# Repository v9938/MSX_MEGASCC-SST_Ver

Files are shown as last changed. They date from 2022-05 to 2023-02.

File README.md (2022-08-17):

# MSX MEGA-SCC (似非SCC) SST Flash version  

SCCのFlash CartridgeとしてMEGA-SCC(似非SCC)が有名ですが、
使用しているFlash ROM AM29F040Bの入手が近年難しいのが難点でした。  
  
そこで、入手が容易なSST社のFlash ROMでなんとかならんかと  
HRA!(@thara1129)さんが思いついたAddress入れ替えによるMEGA-SCCを基板化したものが本製品になります。

原案：  
<https://github.com/hra1129/MSX_MegaSCC_for_SST39SF040>

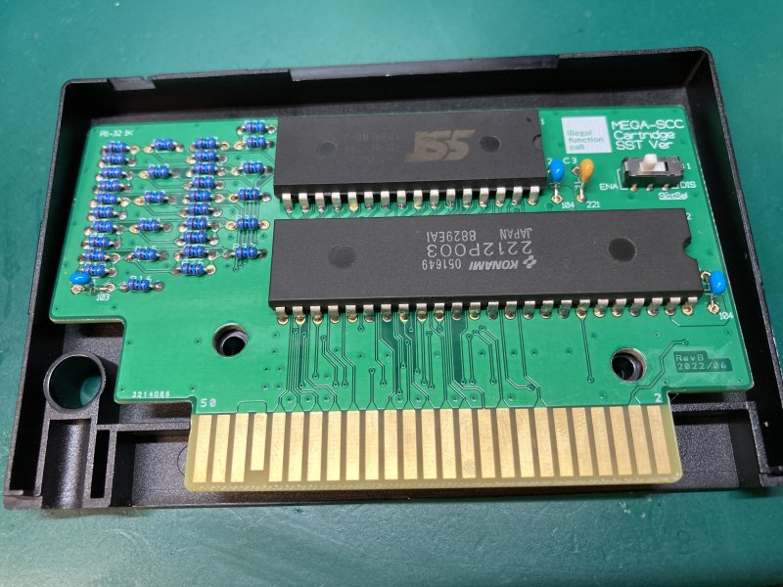
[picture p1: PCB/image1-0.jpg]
  

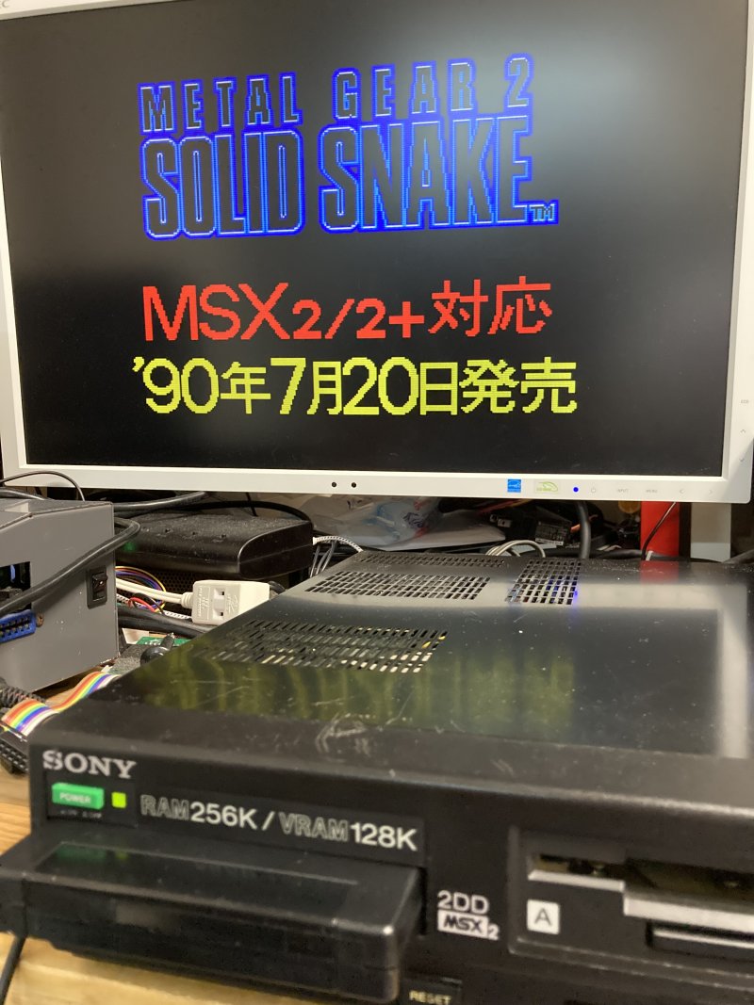
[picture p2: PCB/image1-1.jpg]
  

## ■ 本製品のキット頒布について

下記2ショップで取り扱っていただいています。  

家電のKENちゃん  
<https://www.kadenken.com/view/item/000000001450>  

BEEPさん  
<https://www.beep-shop.com/ec/products/detail/26575>  

本キットの組み立てにはSCC (2212P003) を実カートリッジから取り外す必要があります。  

DACのKONAMI051650については取り外し不要です。  
基板上に等価回路を実装しています。  

シェルはKONAMIのMSX CassetteまたはRGR製のTransparent Cartridge Shell for MSX Konami-styleに対応しています。

## ■ KONAMI純正シェルを使用する方へのお願い（RevA/B 基板）

当方の基板サイズの計測ミスでケースと干渉することが分かりました。  
使用する場合は、干渉する左上3x8mm程度をカットするようにお願いします。（下記図参考)  
なお、当該部分は配線などが無いため動作に影響はありません。  

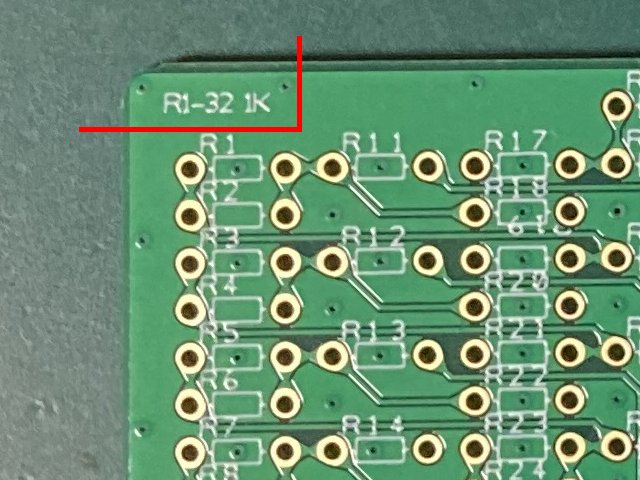
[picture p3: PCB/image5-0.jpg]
  

## ■ SCCとの結線について

HRA!(@thara1129)さんの方法通りです。A12とMA15を入れ替えます。
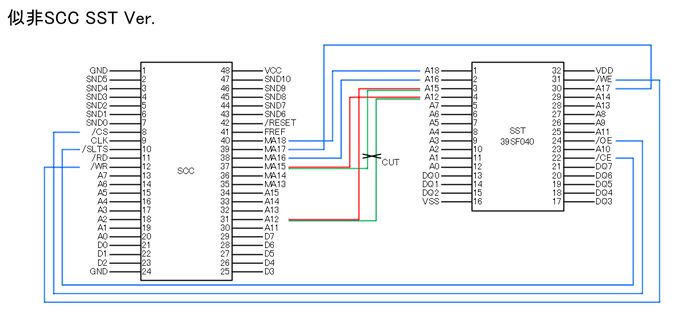
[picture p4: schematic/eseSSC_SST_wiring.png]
  

## ■ カートリッジ基板について

回路図、および基板のガーバデータを同梱しています。  
  
SCCチップ(2212P003)については、実カートリッジから取り外して実装してください。  
DACのKONAMI051650については、取り外しの難易度が高いのでHICの等価回路を基板上に実装しています。  
  
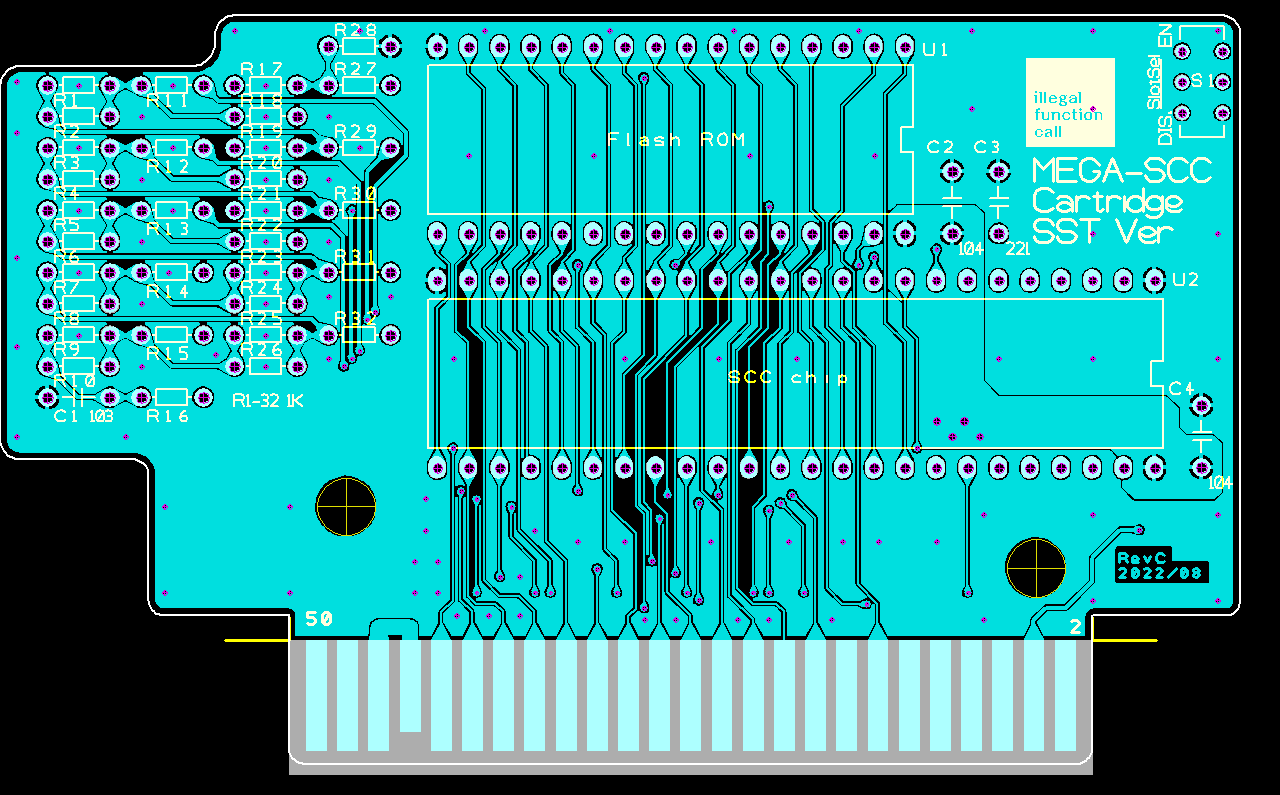
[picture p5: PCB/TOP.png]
  
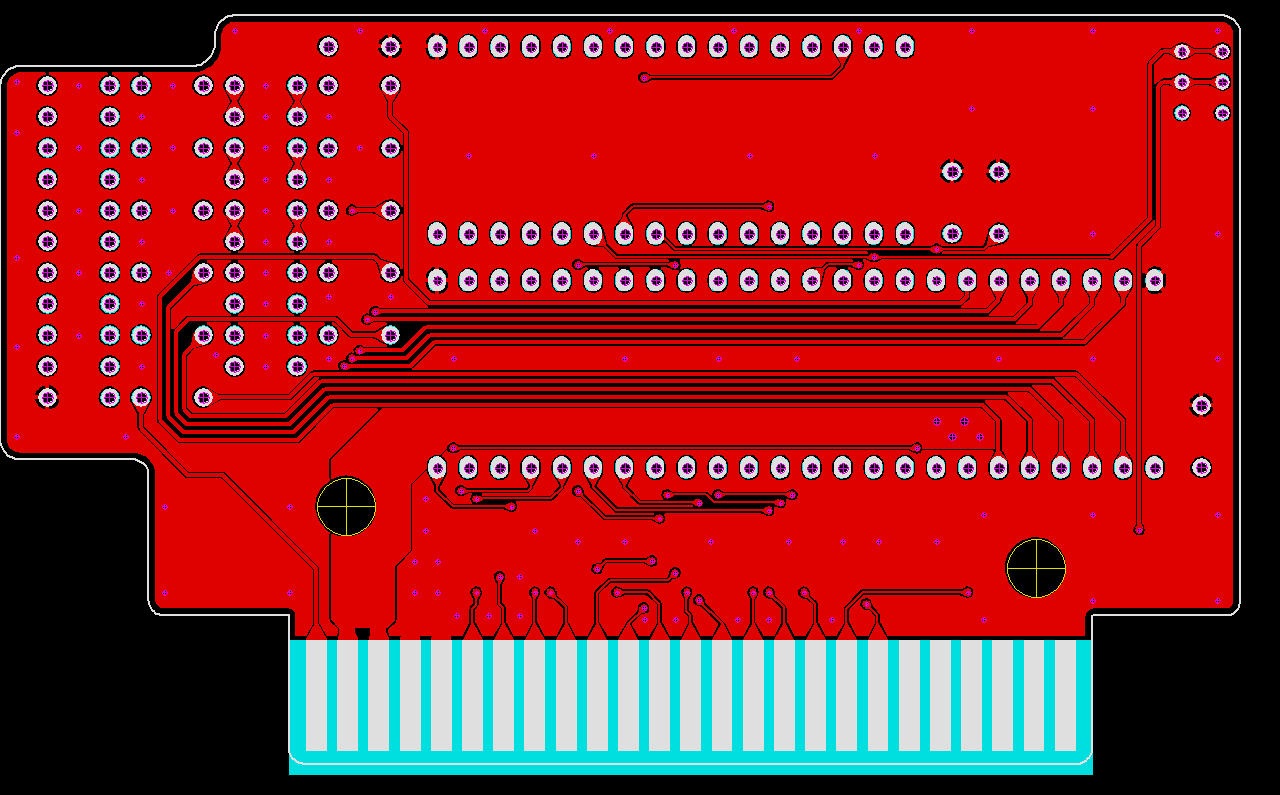
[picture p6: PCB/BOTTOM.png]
    

## ■ 回路図

全体の回路図については下記を参照してください。
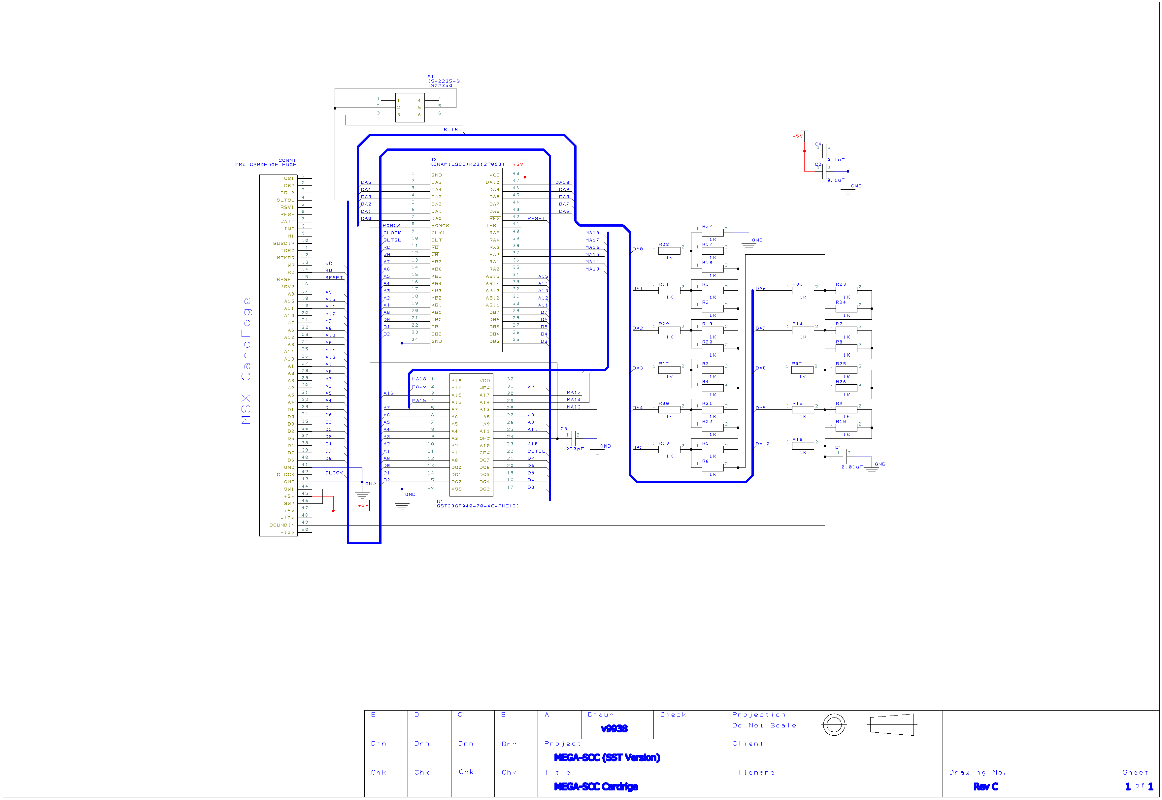
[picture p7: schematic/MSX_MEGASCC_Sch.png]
  

## ■ 部品表

| 部品番号 | 部品名 |
|---|---|
| U1  | Flash ROM SST39SF040 |
| U2  | KONAMI SCC CHIP 2212P003 |
| C1  | 積層セラミック コンデンサー0.01uF (103) |
| C2/C4  | 積層セラミック コンデンサー0.1uF (104) |
| C3  | 積層セラミック コンデンサー220pF (221) |
| R1-32  | 1KΩ(5%) 1/8W |
| S1  | スイッチ IS-2235 (RevB～)|  

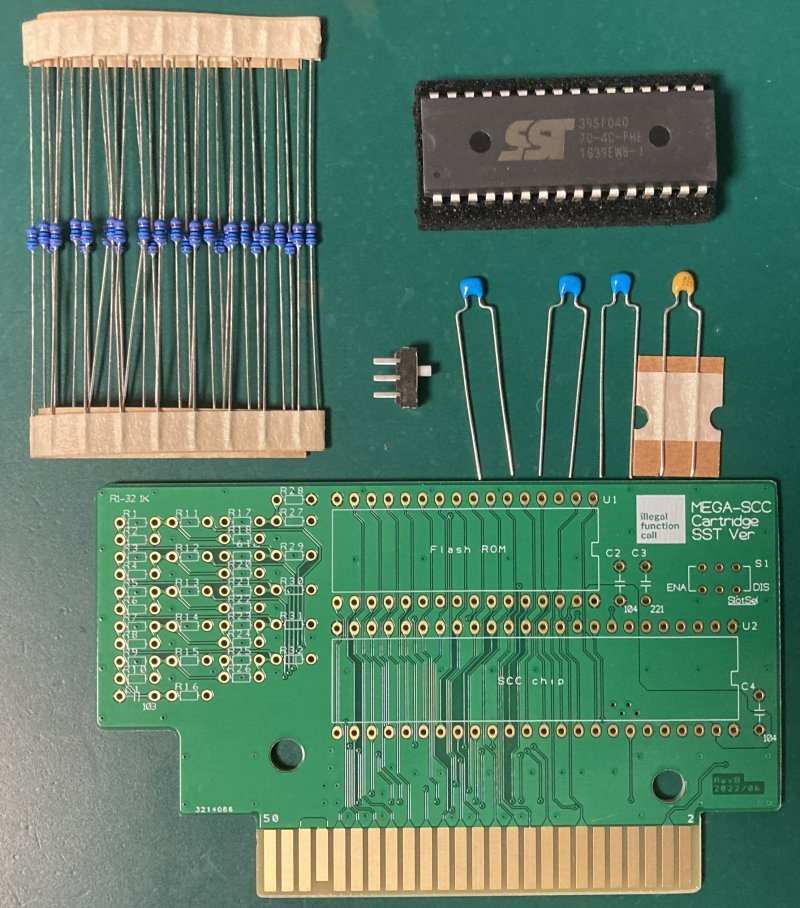
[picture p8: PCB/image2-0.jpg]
  

## ■ 基板の組み立て方法

セオリー通り背の低い部品から半田付けしてください。  
ICソケットを使うとケースに入らなくなるので注意してください。  

1．R1-32を実装  
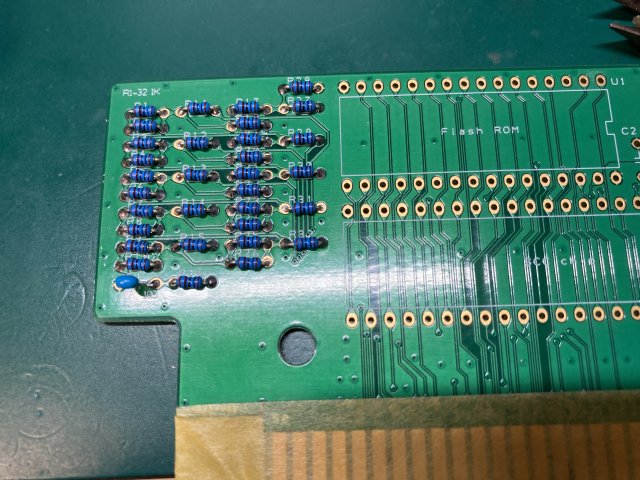
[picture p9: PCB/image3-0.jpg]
  

2．S1/C1-4を実装  
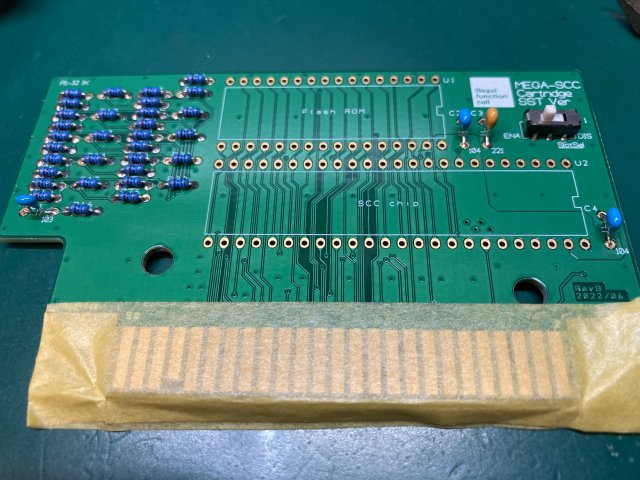
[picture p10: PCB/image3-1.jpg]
  

3．U1/2を実装  
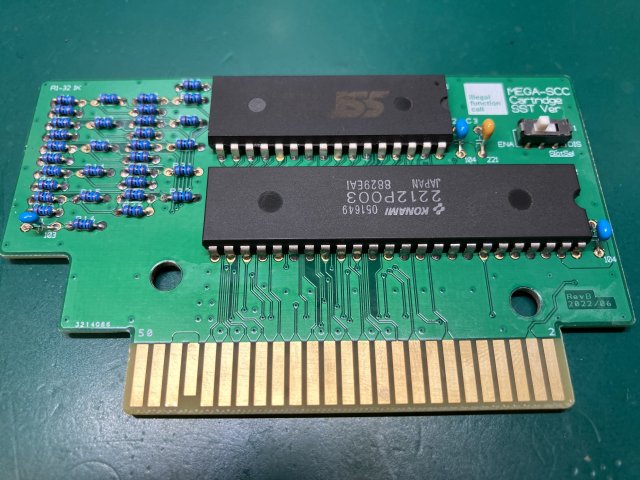
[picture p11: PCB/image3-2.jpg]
  

## ■ 基板上のスイッチについて(RevB以降)

スロット選択信号の有効/無効の切り替えスイッチになっています。  
再書き込みなどで一次的にCartridgeを無効化する場合に使用ください。
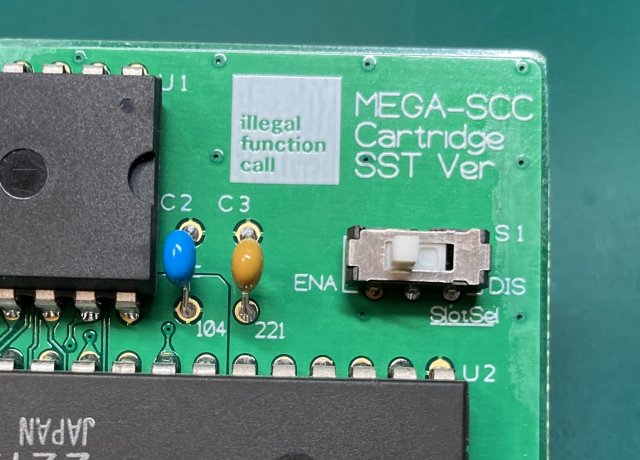
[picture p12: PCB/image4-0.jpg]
  

## ■ Flashの制御方法

BANK0=0x01/BANK1=0x06に設定することで、
Flashのコントロールアドレス2AAAhは4AAAh・コントロールアドレス5555hは6555hにマッピングされます。  

SST系のFlashは、上位アドレスを見てしまうので従来の結線通りにしてしまうと、コントロールアドレスに  
書き込み時にバンクアドレスが切り替わってしまい。上手くコントロールできません。  
それを回避するためにA12とMA15を入れ替えてその問題に対応しています。

なお、CMD体系自体は、AMD系とほぼ同じです。  
BUSYの出方はAMD系と異なるため注意してください。  

参考：  
<https://www.microchip.com/wwwproducts/en/SST39SF010A>  
  
## ■ Flash書き込みプログラム

●書き込み  
`>sstscc.com [書き込みFile名]`  

ソースコードは、z88dkでコンパイル可能です。コンパイルオプションは下記になります。  
`zcc +msx -create-app -subtype=msxdos -lmsxbios  main.c -o xxxx.com`  
  
  HRA!(@thara1129)さん謹製のwrtsstの方が動作が速いのでおすすめです＾＾；  
<https://github.com/hra1129/MSX_MegaSCC_for_SST39SF040/tree/main/tools>

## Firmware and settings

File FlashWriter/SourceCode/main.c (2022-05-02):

#include <stdio.h>
#include <msx.h>
#include <sys/ioctl.h>

#define VERSION "V1.0"
#define DATE "2022/05"

#define BUF_SIZE 128

//#include <msx/gfx.h>

unsigned char SelectSlot;		//Select Slot number
unsigned char eseBank;			//eseSCC 6000-7fffh Bank number
unsigned char *addressWrite;	//Write pointer
unsigned char eseSlot;			//eseSCC Slot number
unsigned char maxBank;			//ROM Size
int findId;						//Flash ID


//Assembler SubRoutine
void asmCalls(){
#asm
chengePageSlot:
	di
    ld a,(_SelectSlot)	;Slot Number
    ld hl,04000h		;Select page 1
    call 0024h			;call ENASLT

    ld a,(_SelectSlot)	;Slot Number
    ld hl,08000h		;Select page 2
    call 0024h			;call ENASLT

	ld hl,04AAAh		;Flash Address 1st 0x2AAA
	ld de,06555h		;Flash Address 2nd 0x5555

	ld a,(_eseBank)		;Bank Select A000h-Bfffh
	ld (0B000h),a

	ld a,001h			;
    ld (05000h),a		;Bank 0 Page2

	ld a,006h			;
    ld (07000h),a		;Bank 1 Page5
    
	ret

restoreRAMPage:
	ld a,(0f342h)		;Restore RAM Page (RAMAD1)
    ld hl,04000h		;Select page 1
    call 0024h			;call ENASLT

	ld a,(0f343h)		;Restore RAM Page (RAMAD2)
    ld hl,08000h		;Select page 2
    call 0024h			;call ENASLT
	ei
	ret
#endasm
}
void eraseEseSCC() __z88dk_fastcall __naked {
#asm
	call chengePageSlot
    
	ld a,0aah			; Chip-Erase Command 1st
    ld (de),a			; aa-55-80
	ld a,055h
    ld (hl),a
	ld a,080h
    ld (de),a

	ld a,0aah			; Chip-Erase Command 2nd
    ld (de),a			; aa-55-10
	ld a,055h
    ld (hl),a
	ld a,010h
    ld (de),a

	call restoreRAMPage

    ld hl,0fc9eh		;JIFFY address
	ld a,(hl)			;Load INTCNT
	add 06h				;16.6ms x 6 = 99.6ms
busyWait:
	cp	(hl)			;Check INTCNT
	jr nz,busyWait		;Wait Loop
	ret
#endasm
}

void writeEseSCC(unsigned char *bufferAddress)
{
#asm
	push hl					;Backup Buffer address
	call chengePageSlot		;4000-bfffh Change eseSCC Slot 
	pop hl

	ld de,(_addressWrite)	;Get buffer address
	ld bc,BUF_SIZE			;Set buffer size
writeLoop:
	ld a,001h				;
    ld (05000h),a			;Bank 0 Page5
	ld a,006h				;
    ld (07000h),a			;Bank 1 Page2

	ld a,0aah				; Flash Byte-Program
    ld (06555h),a			; aa-55-a0
	ld a,055h
    ld (04AAAh),a
	ld a,0A0h
    ld (06555h),a
    ld a,(hl)				; Load Buffer Data
    ld (de),a				; Flash program data
	ld a,(_eseBank)			; Reselect Bank A000h-Bfffh
	ld (0B000h),a
writeWait:	
    ld a,(de)				; Verify program data
    cp (hl)					; Verify check
    jr nz,writeWait			; Wait Byte-Program Time
	inc hl					; Buffer address ++
	inc de					; Flash address ++
	dec bc					; Counter --
	ld a,b					; bc == 00?
	or c 
    jr nz,writeLoop			; Continue loop
	ld (_addressWrite),de	
	call restoreRAMPage
	ret
#endasm
}

int chkEseSCC() __z88dk_fastcall __naked {
#asm
	call chengePageSlot	; 4000-bfffh Change eseSCC Slot 

	ld a,0aah			; Software Product ID Entry aa-55-90-read0-1
    ld (de),a
	ld a,055h
    ld (hl),a
	ld a,090h
    ld (de),a
	ld a,(04000h)		; Read Maker ID
    ld b,a
	ld a,(04001h)		; Read Device ID
    ld c,a
	push bc				; Return value

	ld a,001h				;
    ld (05000h),a			;Bank 0 Page5
	ld a,006h				;
    ld (07000h),a			;Bank 1 Page2
	
	ld a,0aah			; Reset Command sequence aa-55-f0
    ld (de),a
	ld a,055h
    ld (hl),a
	ld a,0f0h
    ld (de),a

	call restoreRAMPage	; 4000-bfffh Restore RAM Slot
	pop hl
	ret
#endasm
}

void findEseSCC(void){
	unsigned char i;
	unsigned int chipId;
	
	if ((SelectSlot & 0xf0) == 0x80){
		//Expantion Slot Check
		for (i=0;i<4;i++){
			chipId = chkEseSCC();
			if ((chipId & 0xff00) == 0xbf00) {		//0xBF SST Maker ID
				eseSlot = SelectSlot;
				findId = chipId;
			}
			SelectSlot = SelectSlot + 4;
		}
	}else{
		//Master Slot Check
		chipId = chkEseSCC();
		if ((chipId & 0xff00) == 0xbf00) {			//0xBF SST Maker ID
			eseSlot = SelectSlot;
			findId = chipId;
		}
	}
}
	
int main(int argc,char *argv[])
{

	FILE *fp;
	unsigned char ReadData[BUF_SIZE];
	int i;
	unsigned char dat;
	
	
	printf("MEGA SCC SST Writer %s\n",VERSION);
	printf("Copyrigth %s @v9938\n\n",DATE);

	if (argc<2){
		printf( "sstscc [rom files]\n");
		printf( "This program will write the selected file to the flash ROM.\n");
		return 0;
	}

	printf("Search Flash ... ");
	eseSlot = 0;
	//Slot 1 Search
	SelectSlot = *((unsigned char *)0xfcc2) | 0x01;		//EXPTBL (SLOT1)
	findEseSCC();
	//Slot 2 Search
	SelectSlot = *((unsigned char *)0xfcc3) | 0x02;		//EXPTBL (SLOT2)
	findEseSCC();
	//Slot 3 Search
	SelectSlot = *((unsigned char *)0xfcc4) | 0x03;		//EXPTBL (SLOT3)
	findEseSCC();

	if (eseSlot == 0) {								// Not find eseSCC
		printf("NOT find\n");
		printf("Bye...\n");
		return -1;
	}else{
		printf("Find!\n");
		printf("\nSlot: %02x",eseSlot);
	}

	//Flash Type Check
	printf("\nFlash Type: ");
	if ((findId & 0x00ff) == 0xb5){
		printf("SST39SF010A\n");
		maxBank = 0xf;
	}else if ((findId & 0x00ff) == 0xb6){
		printf("SST39SF020A\n");
		maxBank = 0x1f;
	}else if ((findId & 0x00ff) == 0xb7){
		printf("SST39SF040A\n");
		maxBank = 0x3f;
	}else{
		printf("Unknown Flash\n");
		printf("Bye...\n");
		return -1;
	}

	//ROM File Open
	fp =fopen(argv[1],"rb");
    if( fp == NULL ){
    	printf( "File can't open... %s\n", argv[1]);
    	return -1;
    }

	//Bank set
	SelectSlot = eseSlot;
	eseBank = 0;
	addressWrite = (unsigned char *)0xA000;

	//Flash Erase
	printf("\nFlash Erase ... ");
	eraseEseSCC();
	printf("Done.");

	//Flash Write
	printf("\nFlash Write");
	printf("\n     0123456789ABCDEF");
	printf("\n0x00 .");
	
	while (1){

		fread(ReadData,sizeof ReadData, 1, fp);		//Read Buffer

		if (feof(fp) != NULL) break;				//File End ?
		if (ferror(fp) != NULL) {					//EIO Error?
			printf("File IO Error!\n");
			fclose(fp);
			return -1;
		}

		//Parameter Check
		if (addressWrite >= 0xC000){					// 6000-7fffh Write finsh?
			addressWrite = (unsigned char *)0xA000;		// Yes! Return write start address
			if (eseBank < maxBank) {					// ROM size check?
				eseBank++;								// OK! write next bank
				if ((eseBank & 0x0f)== 0){				// Display progress
					printf("\n0x%02x .",eseBank);		//
				}else{
					printf(".");						// Display progress
				}

			}else{
				printf("\nROM size is FULL.");			// Ummm.ROM is FULL
				break;									//
			}
		}
		writeEseSCC(ReadData);						//Bank Write Data
	}
	fclose(fp);

	dat = 0;

	while(1){
		

		if (addressWrite >= 0xC000){					// 6000-7fffh Write finsh?
			addressWrite = (unsigned char *)0xA000;		// Yes! Return write start address
			if (eseBank < maxBank) {					// ROM size check?
				eseBank++;								// OK! write next bank
				for (i=0;i<BUF_SIZE;i++){
					ReadData[i]=dat;
				}
				dat++;
				if ((eseBank & 0x0f)== 0){				// Display progress
					printf("\n0x%02x -",eseBank);		//
				}else{
					printf("-");						// Display progress
				}

			}else{
				break;
			}
		}
		writeEseSCC(ReadData);						//Bank Write Data
	}
	
	
	printf("\n\nDone. Thank you using!\n");
	return 0;

}

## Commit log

2022-05-07 PCB design data added
    Gerber files and schematic data were added.
    [MSX_MEGASCC - Bottom Copper (Resist).gbr, MSX_MEGASCC - Bottom Copper.gbr, MSX_MEGASCC - Drill Ident Drawing - [Through Hole].gbr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]
2022-08-11 Fixed document for RevB PCB
    Add some information for RevB PCB
2022-08-17 Added case of using the genuine KONAMI shell
2023-02-18 Update PCB Revision C
    PCB Data change Rev C.
    Fixed PCB outline for KONAMI Shell.
    [MSX_MEGASCC - Bottom Copper (Resist).gbr, MSX_MEGASCC - Bottom Copper.gbr, MSX_MEGASCC - Drill Ident Drawing - [Through Hole].gbr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]
